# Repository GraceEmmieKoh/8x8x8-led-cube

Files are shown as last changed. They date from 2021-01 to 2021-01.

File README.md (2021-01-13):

# 8x8x8-led-cube
Eagle project for 8x8x8 LED Cube (v5) PCB, using ESP32

This project was largely inspired by chr's LED Cube Instructables build here: https://www.instructables.com/Led-Cube-8x8x8/

I used an ESP32 as the main microcontroller. The LED's are controlled by switching on/off columns with 74HC595's, and by alternating between layers with PN2222's. The circuit requires a 12V power supply, which is stepped down to 5V using a LM2678-ADJ.
The cube is connected to the PCB through nine 8-pin JST connectors. Eight connectors are used to control each column (8 * 8 = 64), and one connector is used to control between each layer.

This project is currently unfinished. I plan to add a Fusion 360 CAD model to house the PCB, as well as code for the cube.

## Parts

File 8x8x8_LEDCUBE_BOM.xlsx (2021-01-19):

DigiKey # | Name | Amt needed | Amt to order | Price per 1 | Price for order
 | 1000pcs 3mm diffused LED's with long legs | 1 | 0 |  | 0.000
 | 20AWG 100' long tinned wire | 1 | 0 |  | 0.000
 |  |  |  |  | 0.000
 | 12V 2A power supply | 1 | 0
 | E-switch | 1 | 0
 | ESP32 DEVKIT v1 DOIT | 1 | 0
 | 15-pin 0.1" header connector | 2 | 0
277-1667-ND | 2-pin terminal block connector | 4 | 4 | 0.430 | 1.72
 | 5mm green LED | 1 | 0
1568-1212-ND | 5mm LED holder | 1 | 1 | 0.500 | 0.50
EG1900-ND | Panel push button | 2 | 2 | 1.870 | 3.74
 | SN74HC595 shift register | 8 | 0
ICS-316-T | 16-DIP IC socket | 8 | 10 | 0.168 | 1.68
LM2678T-ADJ/NOPB-ND | LM2678T-ADJ 5V buck converter | 1 | 2 | 5.830 | 11.66
A10764-ND | TO-220 (LM2678T) heat sink | 1 | 1 | 0.200 | 0.20
 | 8-pin JST PH 2.0mm pitch male header | 9 | 0
 | 8-pin JST PH 2.0mm pitch 300mm long female wire | 9 | 0
PN2222AFS-ND | PN2222A NPN transistor | 16 | 20 | 0.192 | 3.84
497-8487-2-ND | STPS5L60S schottkey diode | 1 | 2 | 0.58 | 1.16
AIAP-03-220K-ND | 22uH inductor | 1 | 2 | 1.49 | 2.98
A129743TR-ND | 0805 330Ohm resistor | 65 | 100 | 0.018 | 1.79
RNCP0805FTD1K00TR-ND | 0805 1kOhm resistor | 19 | 25 | 0.070 | 1.75
P123841TR-ND | 0805 3.61kOhm resistor | 1 | 2 | 0.100 | 0.20
RNCP0805FTD10K0TR-ND | 0805 10kOhm resistor | 10 | 15 | 0.070 | 1.05
1276-1015-1-ND | 0805 0.01uF ceramic capacitor | 1 | 2 | 0.1 | 0.20
1276-1003-1-ND | 0805 0.1uF ceramic capacitor | 10 | 15 | 0.048 | 0.72
1276-6455-1-ND | 0805 10uF ceramic capacitor | 3 | 5 | 0.11 | 0.55 | x
P12397-ND | 220uF electrolytic capacitor | 1 | 2 | 0.64 | 1.28
P15331CT-ND | 1000uF electrolytic capacitor | 1 | 2 | 0.66 | 1.32
 |  |  |  |  |  | Total Price =
 |  |  |  |  |  | 34.12
ALL COSTS: | 135.42
where | what | how much
JLCPCB | PCB | 30.43
DigiKey | Most of the electronics parts | 48.17
eBay | LED's | 13.91
eBay | ESP32 DEVKIT v1 | 7.62
eBay | JST connectors | 16.04
eBay | Power supply | 5.9
Amazon | Tinned wire | 13.35

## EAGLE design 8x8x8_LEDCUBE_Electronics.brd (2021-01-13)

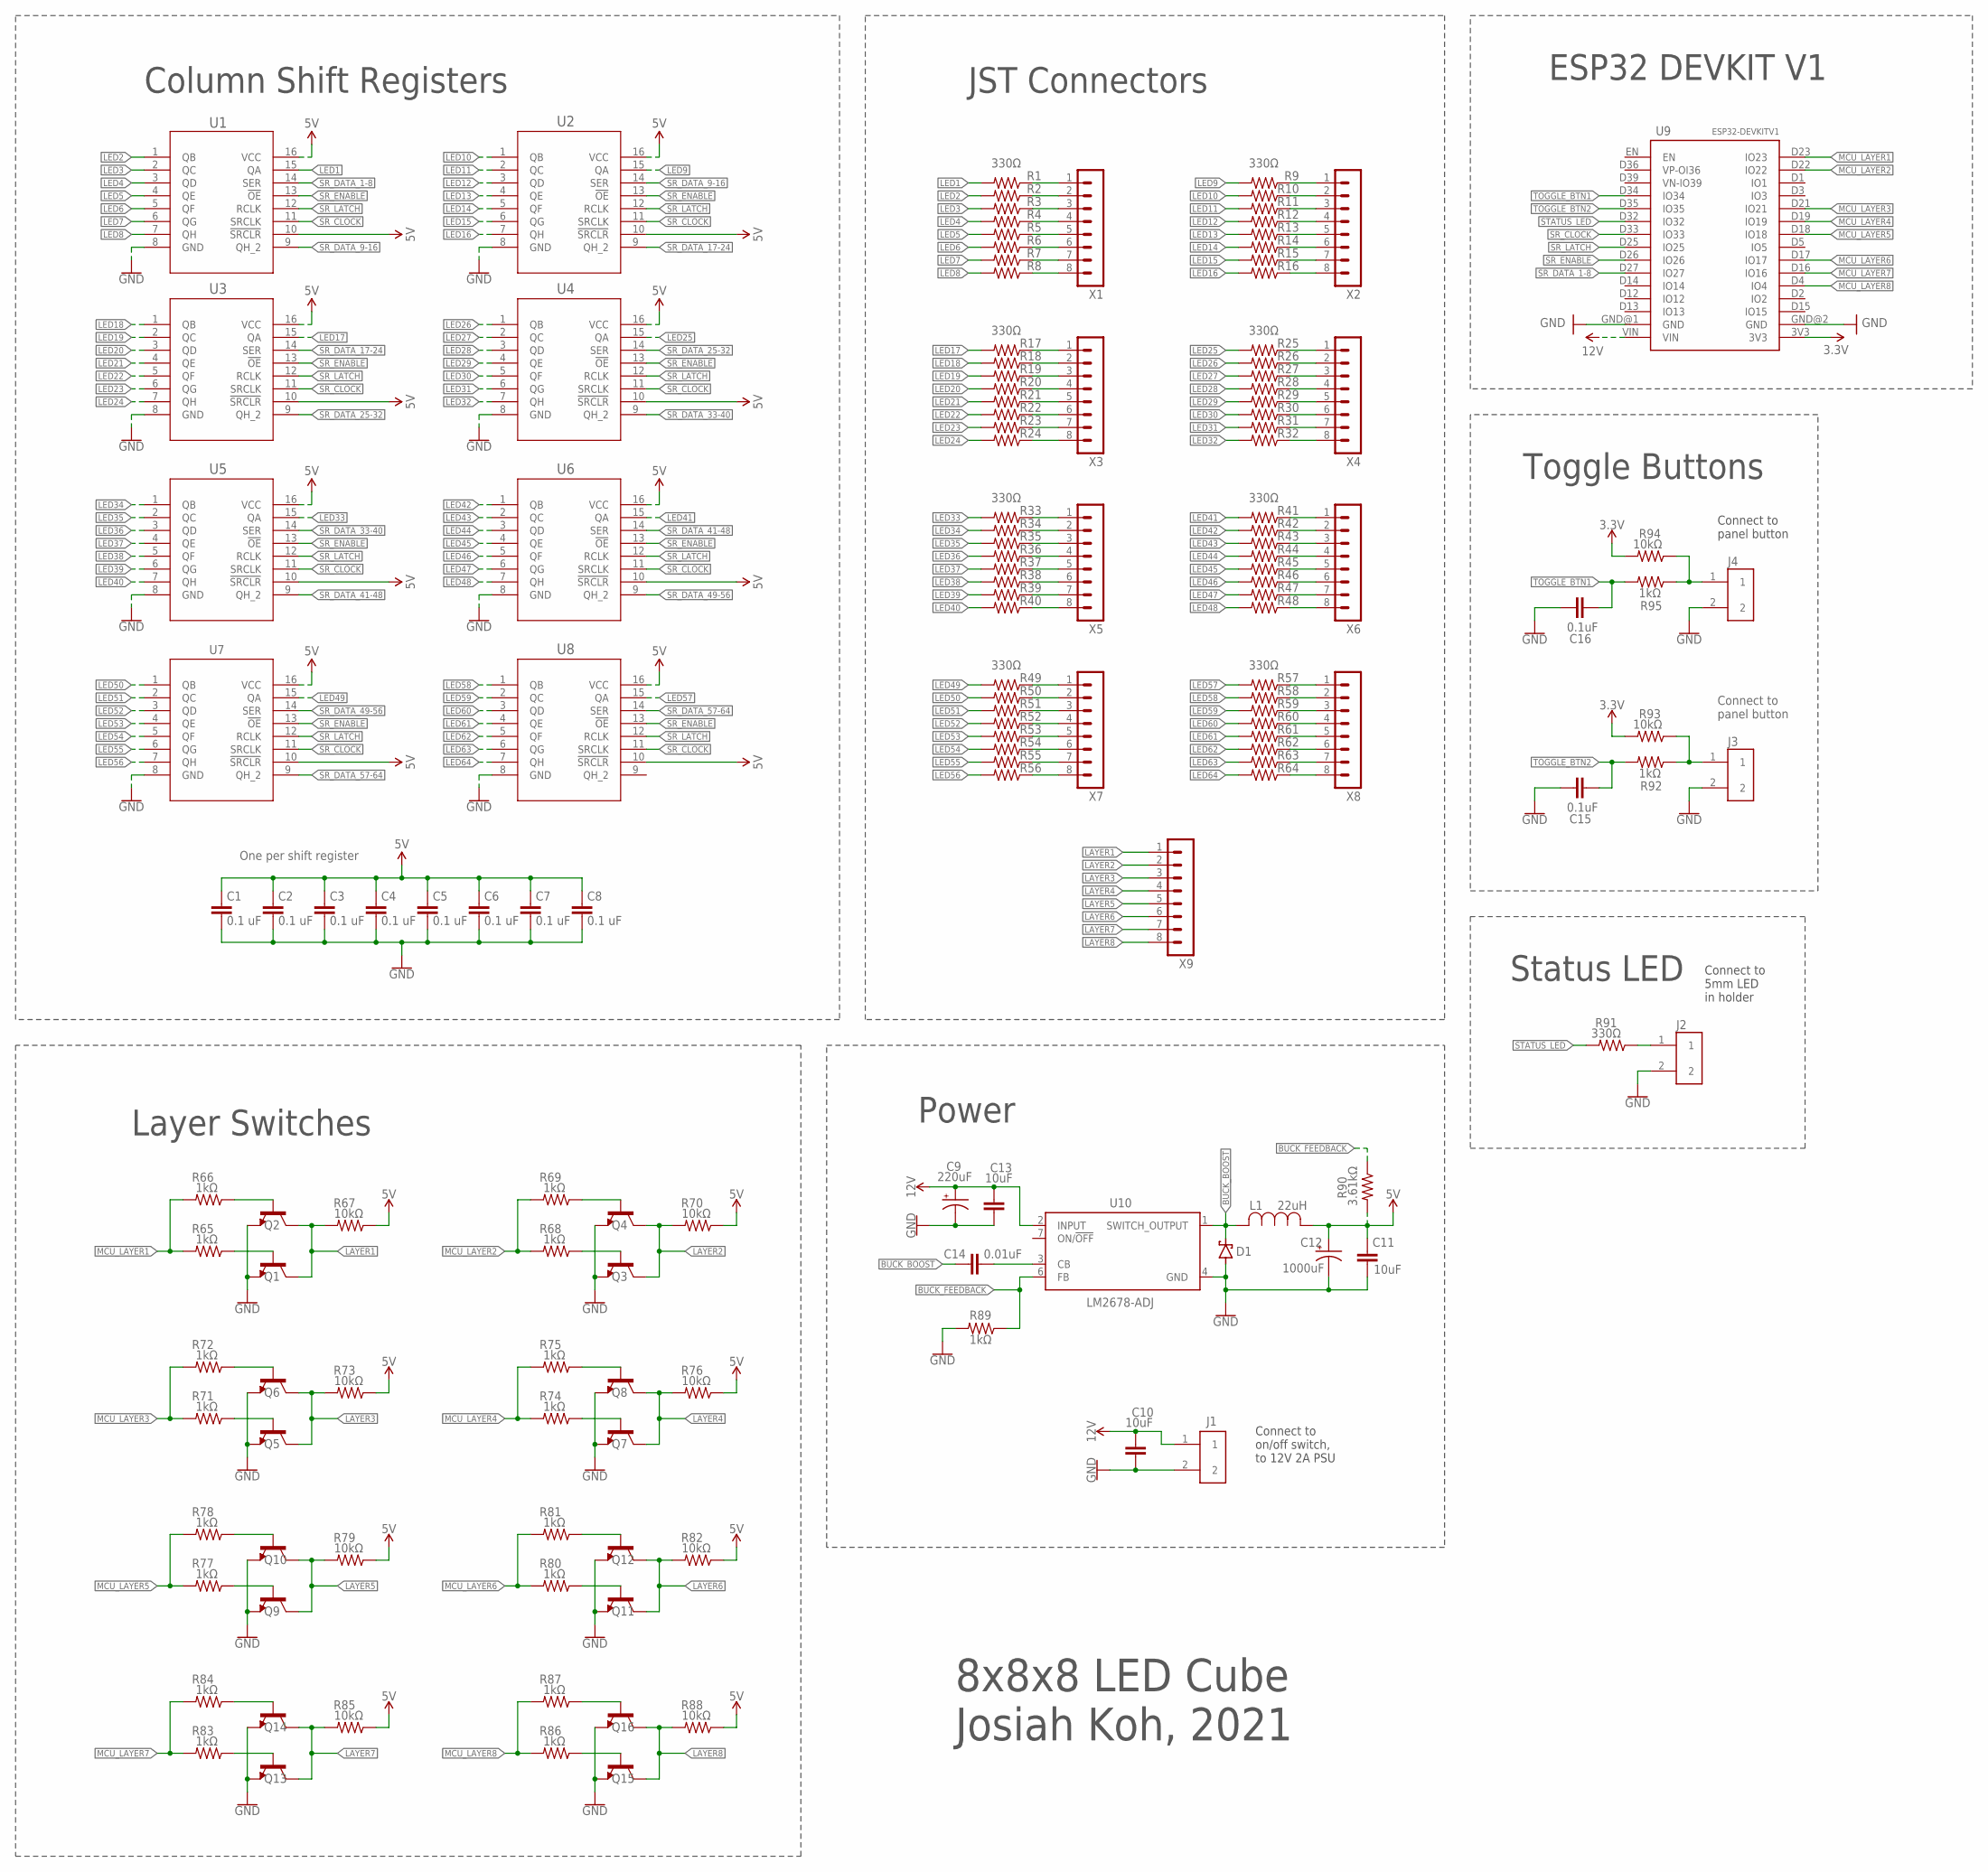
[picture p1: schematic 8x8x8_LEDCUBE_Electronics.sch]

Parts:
C1, C2, C3, C4, C5, C6, C7, C8: 0.1 uF; C0805
C9: 220uF; E3,5-10
C10, C11, C13: 10uF; C0805
C12: 1000uF; E3,5-10
C14: 0.01uF; C0805
C15, C16: 0.1uF; C0805
D1: STPS5L60S; SMC
J1, J2, J3, J4: 1935161; PHOENIX_1935161
L1: 22uH; AIAP-03_ABR
Q1, Q2, Q3, Q4, Q5, Q6, Q7, Q8, Q9, Q10, Q11, Q12, Q13, Q14, Q15, Q16: 600mA/40V; TO-92
R1, R2, R3, R4, R5, R6, R7, R8, R9, R10, R11, R12, R13, R14, R15, R16, R17, R18, R19, R20, R21, R22, R23, R24, R25, R26, R27, R28, R29, R30, R31, R32, R33, R34, R35, R36, R37, R38, R39, R40, R41, R42, R43, R44, R45, R46, R47, R48, R49, R50, R51, R52, R53, R54, R55, R56, R57, R58, R59, R60, R61, R62, R63, R64, R91: 330Ω; R0805
R65, R66, R68, R69, R71, R72, R74, R75, R77, R78, R80, R81, R83, R84, R86, R87, R89, R92, R95: 1kΩ; R0805
R67, R70, R73, R76, R79, R82, R85, R88, R93, R94: 10kΩ; R0805
R90: 3.61kΩ; R0805
U1, U2, U3, U4, U5, U6, U7, U8: SN74HC595N; N16
U9: ESP32DEVKITV1; ESP32-DEVKITV1
U10: LM2678-ADJ; TO127P1041X469X2199-7N
X1, X2, X3, X4, X5, X6, X7, X8, X9: B8B-PH-KL; B8B-PH-K-S

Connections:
3.3V: R93.2, R94.2, U9.3V3
5V: C1.1, C2.1, C3.1, C4.1, C5.1, C6.1, C7.1, C8.1, C11.1, C12.+, L1.1, R67.1, R70.1, R73.1, R76.1, R79.1, R82.1, R85.1, R88.1, R90.2, U1.10 (!SRCLR), U1.16 (VCC), U2.10 (!SRCLR), U2.16 (VCC), U3.10 (!SRCLR), U3.16 (VCC), U4.10 (!SRCLR), U4.16 (VCC), U5.10 (!SRCLR), U5.16 (VCC), U6.10 (!SRCLR), U6.16 (VCC), U7.10 (!SRCLR), U7.16 (VCC), U8.10 (!SRCLR), U8.16 (VCC)
12V: C9.+, C10.1, C13.1, J1.1, U9.VIN, U10.2 (INPUT)
BTN1_CONNECTOR: J4.1, R94.1, R95.1
BTN2_CONNECTOR: J3.1, R92.1, R93.1
BUCK_BOOST: C14.1, D1.C, L1.2, U10.1 (SWITCH_OUTPUT)
BUCK_FEEDBACK: R89.1, R90.1, U10.6 (FB)
GND: C1.2, C2.2, C3.2, C4.2, C5.2, C6.2, C7.2, C8.2, C9.-, C10.2, C11.2, C12.-, C13.2, C15.2, C16.2, D1.A, J1.2, J2.2, J3.2, J4.2, Q1.3 (E), Q2.3 (E), Q3.3 (E), Q4.3 (E), Q5.3 (E), Q6.3 (E), Q7.3 (E), Q8.3 (E), Q9.3 (E), Q10.3 (E), Q11.3 (E), Q12.3 (E), Q13.3 (E), Q14.3 (E), Q15.3 (E), Q16.3 (E), R89.2, U1.8 (GND), U2.8 (GND), U3.8 (GND), U4.8 (GND), U5.8 (GND), U6.8 (GND), U7.8 (GND), U8.8 (GND), U9.GND@1 (GND), U9.GND@2 (GND), U10.4 (GND)
LAYER1: Q1.1 (C), Q2.1 (C), R67.2, X9.1
LAYER2: Q3.1 (C), Q4.1 (C), R70.2, X9.2
LAYER3: Q5.1 (C), Q6.1 (C), R73.2, X9.3
LAYER4: Q7.1 (C), Q8.1 (C), R76.2, X9.4
LAYER5: Q9.1 (C), Q10.1 (C), R79.2, X9.5
LAYER6: Q11.1 (C), Q12.1 (C), R82.2, X9.6
LAYER7: Q13.1 (C), Q14.1 (C), R85.2, X9.7
LAYER8: Q15.1 (C), Q16.1 (C), R88.2, X9.8
LED1: R1.2, U1.15 (QA)
LED2: R2.2, U1.1 (QB)
LED3: R3.2, U1.2 (QC)
LED4: R4.2, U1.3 (QD)
LED5: R5.2, U1.4 (QE)
LED6: R6.2, U1.5 (QF)
LED7: R7.2, U1.6 (QG)
LED8: R8.2, U1.7 (QH)
LED9: R9.2, U2.15 (QA)
LED10: R10.2, U2.1 (QB)
LED11: R11.2, U2.2 (QC)
LED12: R12.2, U2.3 (QD)
LED13: R13.2, U2.4 (QE)
LED14: R14.2, U2.5 (QF)
LED15: R15.2, U2.6 (QG)
LED16: R16.2, U2.7 (QH)
LED17: R17.2, U3.15 (QA)
LED18: R18.2, U3.1 (QB)
LED19: R19.2, U3.2 (QC)
LED20: R20.2, U3.3 (QD)
LED21: R21.2, U3.4 (QE)
LED22: R22.2, U3.5 (QF)
LED23: R23.2, U3.6 (QG)
LED24: R24.2, U3.7 (QH)
LED25: R25.2, U4.15 (QA)
LED26: R26.2, U4.1 (QB)
LED27: R27.2, U4.2 (QC)
LED28: R28.2, U4.3 (QD)
LED29: R29.2, U4.4 (QE)
LED30: R30.2, U4.5 (QF)
LED31: R31.2, U4.6 (QG)
LED32: R32.2, U4.7 (QH)
LED33: R33.2, U5.15 (QA)
LED34: R34.2, U5.1 (QB)
LED35: R35.2, U5.2 (QC)
LED36: R36.2, U5.3 (QD)
LED37: R37.2, U5.4 (QE)
LED38: R38.2, U5.5 (QF)
LED39: R39.2, U5.6 (QG)
LED40: R40.2, U5.7 (QH)
LED41: R41.2, U6.15 (QA)
LED42: R42.2, U6.1 (QB)
LED43: R43.2, U6.2 (QC)
LED44: R44.2, U6.3 (QD)
LED45: R45.2, U6.4 (QE)
LED46: R46.2, U6.5 (QF)
LED47: R47.2, U6.6 (QG)
LED48: R48.2, U6.7 (QH)
LED49: R49.2, U7.15 (QA)
LED50: R50.2, U7.1 (QB)
LED51: R51.2, U7.2 (QC)
LED52: R52.2, U7.3 (QD)
LED53: R53.2, U7.4 (QE)
LED54: R54.2, U7.5 (QF)
LED55: R55.2, U7.6 (QG)
LED56: R56.2, U7.7 (QH)
LED57: R57.2, U8.15 (QA)
LED58: R58.2, U8.1 (QB)
LED59: R59.2, U8.2 (QC)
LED60: R60.2, U8.3 (QD)
LED61: R61.2, U8.4 (QE)
LED62: R62.2, U8.5 (QF)
LED63: R63.2, U8.6 (QG)
LED64: R64.2, U8.7 (QH)
MCU_LAYER1: R65.2, R66.2, U9.D23 (IO23)
MCU_LAYER2: R68.2, R69.2, U9.D22 (IO22)
MCU_LAYER3: R71.2, R72.2, U9.D21 (IO21)
MCU_LAYER4: R74.2, R75.2, U9.D19 (IO19)
MCU_LAYER5: R77.2, R78.2, U9.D18 (IO18)
MCU_LAYER6: R80.2, R81.2, U9.D17 (IO17)
MCU_LAYER7: R83.2, R84.2, U9.D16 (IO16)
MCU_LAYER8: R86.2, R87.2, U9.D4 (IO4)
unnamed: Q1.2 (B), R65.1
unnamed: Q2.2 (B), R66.1
unnamed: Q3.2 (B), R68.1
unnamed: Q4.2 (B), R69.1
unnamed: Q5.2 (B), R71.1
unnamed: Q6.2 (B), R72.1
unnamed: Q7.2 (B), R74.1
unnamed: Q8.2 (B), R75.1
unnamed: Q9.2 (B), R77.1
unnamed: Q10.2 (B), R78.1
unnamed: Q11.2 (B), R80.1
unnamed: Q12.2 (B), R81.1
unnamed: Q13.2 (B), R83.1
unnamed: Q14.2 (B), R84.1
unnamed: Q15.2 (B), R86.1
unnamed: Q16.2 (B), R87.1
unnamed: J2.1, R91.1
unnamed: R1.1, X1.1
unnamed: C14.2, U10.3 (CB)
unnamed: R2.1, X1.2
unnamed: R3.1, X1.3
unnamed: R4.1, X1.4
unnamed: R5.1, X1.5
unnamed: R6.1, X1.6
unnamed: R7.1, X1.7
unnamed: R8.1, X1.8
unnamed: R9.1, X2.1
unnamed: R10.1, X2.2
unnamed: R11.1, X2.3
unnamed: R12.1, X2.4
unnamed: R13.1, X2.5
unnamed: R14.1, X2.6
unnamed: R15.1, X2.7
unnamed: R16.1, X2.8
unnamed: R17.1, X3.1
unnamed: R18.1, X3.2
unnamed: R19.1, X3.3
unnamed: R20.1, X3.4
unnamed: R21.1, X3.5
unnamed: R22.1, X3.6
unnamed: R23.1, X3.7
unnamed: R24.1, X3.8
unnamed: R25.1, X4.1
unnamed: R26.1, X4.2
unnamed: R27.1, X4.3
unnamed: R28.1, X4.4
unnamed: R29.1, X4.5
unnamed: R30.1, X4.6
unnamed: R31.1, X4.7
unnamed: R32.1, X4.8
unnamed: R33.1, X5.1
unnamed: R34.1, X5.2
unnamed: R35.1, X5.3
unnamed: R36.1, X5.4
unnamed: R37.1, X5.5
unnamed: R38.1, X5.6
unnamed: R39.1, X5.7
unnamed: R40.1, X5.8
unnamed: R41.1, X6.1
unnamed: R42.1, X6.2
unnamed: R43.1, X6.3
unnamed: R44.1, X6.4
unnamed: R45.1, X6.5
unnamed: R46.1, X6.6
unnamed: R47.1, X6.7
unnamed: R48.1, X6.8
unnamed: R49.1, X7.1
unnamed: R50.1, X7.2
unnamed: R51.1, X7.3
unnamed: R52.1, X7.4
unnamed: R53.1, X7.5
unnamed: R54.1, X7.6
unnamed: R55.1, X7.7
unnamed: R56.1, X7.8
unnamed: R57.1, X8.1
unnamed: R58.1, X8.2
unnamed: R59.1, X8.3
unnamed: R60.1, X8.4
unnamed: R61.1, X8.5
unnamed: R62.1, X8.6
unnamed: R63.1, X8.7
unnamed: R64.1, X8.8
SR_CLOCK: U1.11 (SRCLK), U2.11 (SRCLK), U3.11 (SRCLK), U4.11 (SRCLK), U5.11 (SRCLK), U6.11 (SRCLK), U7.11 (SRCLK), U8.11 (SRCLK), U9.D33 (IO33)
SR_DATA_1-8: U1.14 (SER), U9.D27 (IO27)
SR_DATA_9-16: U1.9 (QH_2), U2.14 (SER)
SR_DATA_17-24: U2.9 (QH_2), U3.14 (SER)
SR_DATA_25-32: U3.9 (QH_2), U4.14 (SER)
SR_DATA_33-40: U4.9 (QH_2), U5.14 (SER)
SR_DATA_41-48: U5.9 (QH_2), U6.14 (SER)
SR_DATA_49-56: U6.9 (QH_2), U7.14 (SER)
SR_DATA_57-64: U7.9 (QH_2), U8.14 (SER)
SR_ENABLE: U1.13 (!OE), U2.13 (!OE), U3.13 (!OE), U4.13 (!OE), U5.13 (!OE), U6.13 (!OE), U7.13 (!OE), U8.13 (!OE), U9.D26 (IO26)
SR_LATCH: U1.12 (RCLK), U2.12 (RCLK), U3.12 (RCLK), U4.12 (RCLK), U5.12 (RCLK), U6.12 (RCLK), U7.12 (RCLK), U8.12 (RCLK), U9.D25 (IO25)
STATUS_LED: R91.2, U9.D32 (IO32)
TOGGLE_BTN1: C16.1, R95.2, U9.D34 (IO34)
TOGGLE_BTN2: C15.1, R92.2, U9.D35 (IO35)

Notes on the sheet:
Toggle Buttons
Column Shift Registers
Connect to panel button
One per shift register
Layer Switches
ESP32 DEVKIT V1
Connect to on/off switch, to 12V 2A PSU
Power
Connect to 5mm LED in holder
Status LED
JST Connectors
8x8x8 LED Cube Josiah Koh, 2021

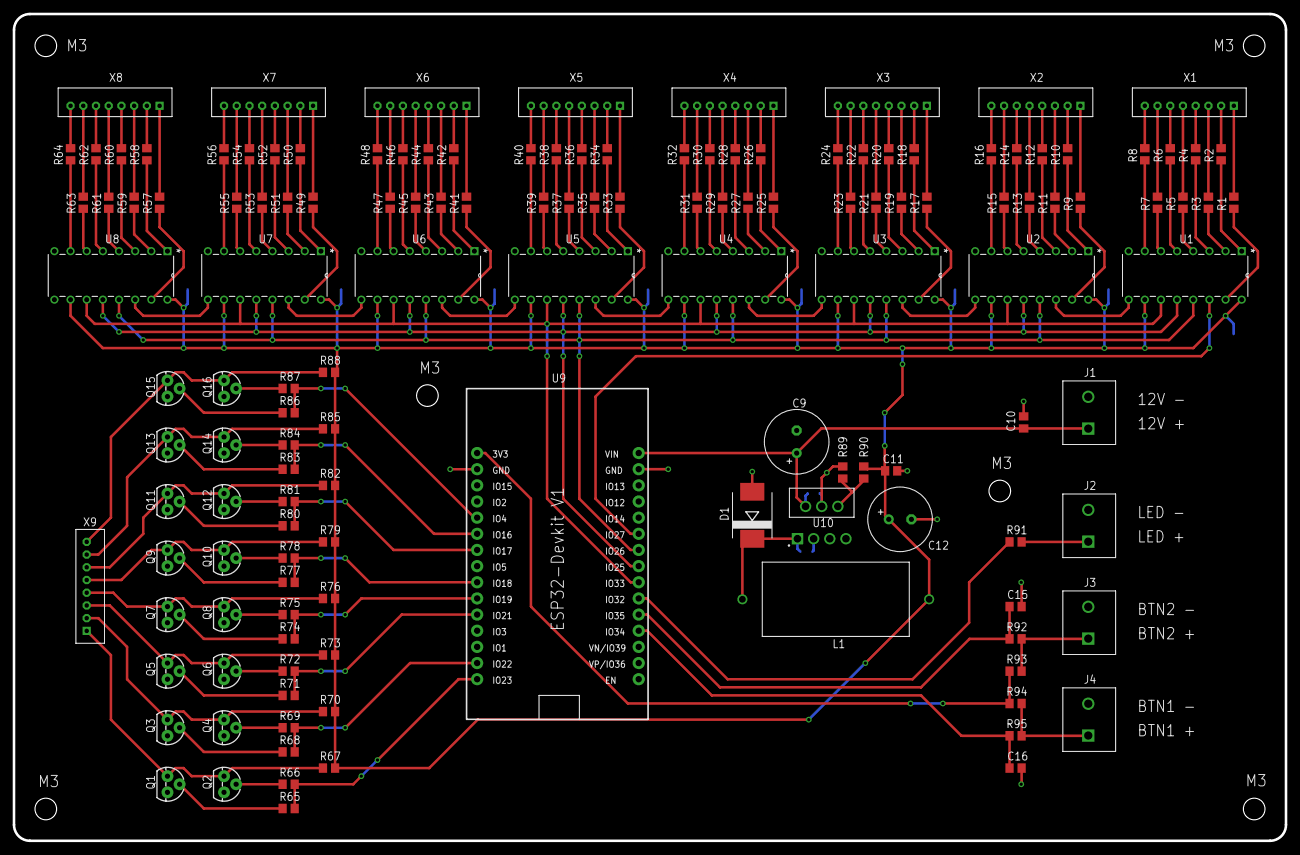
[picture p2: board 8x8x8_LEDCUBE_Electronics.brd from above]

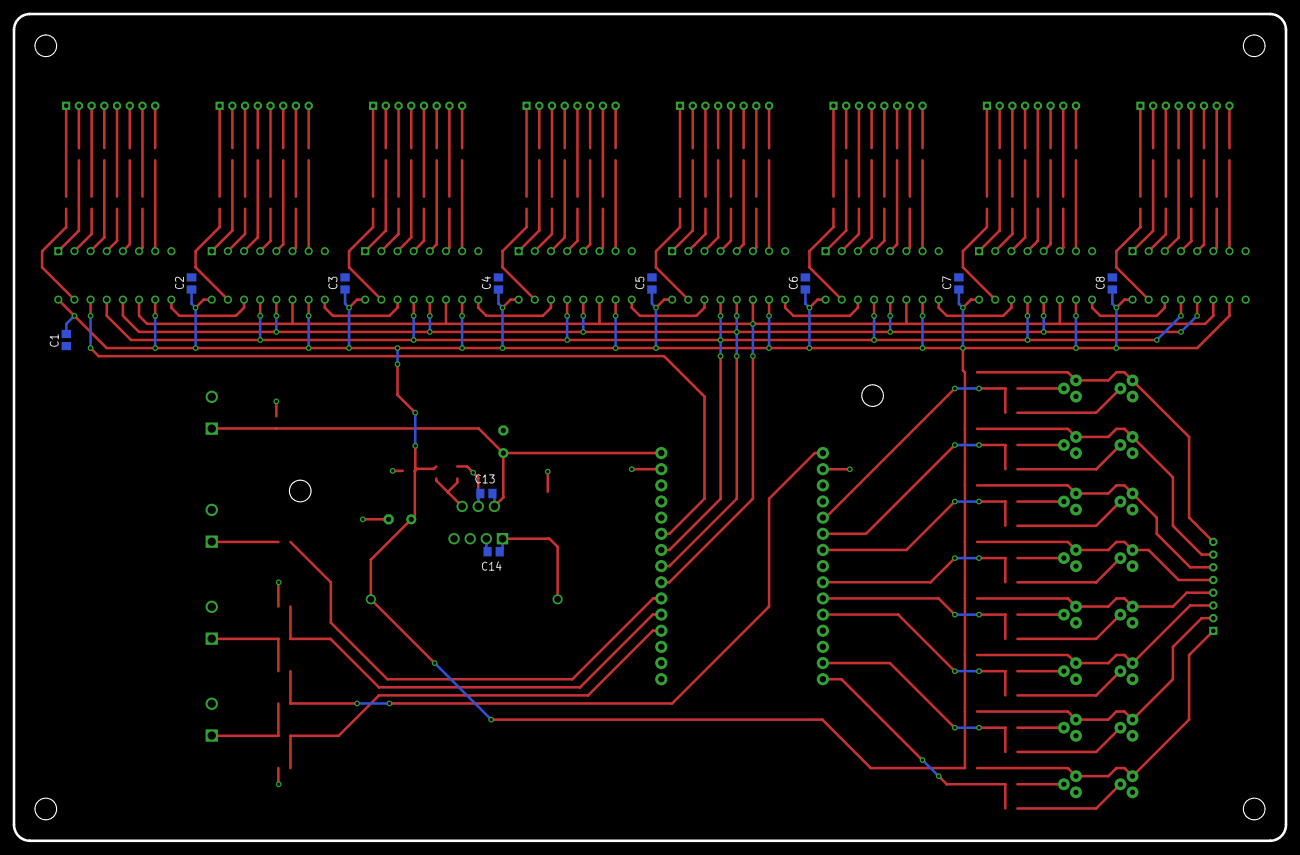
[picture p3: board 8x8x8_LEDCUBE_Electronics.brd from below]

Board: 2 copper layers, 200.0 x 130.0 mm, 152 parts (10 on the bottom side), 184 nets.

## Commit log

2021-01-13 Added files to repo
    [8x8x8_LEDCUBE_Electronics.brd, 8x8x8_LEDCUBE_Electronics.sch]
2021-01-19 Added BOM
    I already own the iems with no DigiKey number
    [8x8x8_LEDCUBE_BOM.xlsx]

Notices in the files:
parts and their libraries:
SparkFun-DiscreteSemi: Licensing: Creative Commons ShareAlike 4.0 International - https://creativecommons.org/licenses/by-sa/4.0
